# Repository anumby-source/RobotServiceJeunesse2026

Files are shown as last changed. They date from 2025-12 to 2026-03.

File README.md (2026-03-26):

# Projet RobotServiceJeunesse2026

# Réflexions préparatoires pour le projet Jeunesse 2026

Le projet Jeunesse aura lieu dans une 1/2 journée dans les vacances pâques 2026 à choisir. 
Faire attention pour la durée: discuter avec les organisateurs pour obtenir réellement les 3 heures de le demie journée.

Principe: On garde le proto de l'année dernière mais avec quelques corrections (et/ou améliorations)

- Meilleurs moteurs plus rapides (choix des roues)
- Mener des tests pour fiabiliser l'utilisation de Esp now
- choisir le CPU de base: Esp32 s2 s3? C3?
  - impact: nombre de DIOs
  - tester la nécessité d'une vraie antenne
  - Nouveau proto (encombrement)
- Pilotage
- nouveau design pour le circuit
- utilisation d'un Microphone?
- IA ? Reconnaissance de symboles plutôt que caractères

- Refaire la télécommande. tests de Fiabilité
- Pb de multicanal sur la communication: tests
- utilisation de Powerbank 5V
- Reconnaissance par le k210 ?

## Organisation:
- distribuer les rôles pour les éléments à re-tester (moteurs, communication, reconnaissance, circuit, achats)
- mettre en place un Github 2026

# Benchmark ESP-now sur ESP32 S3

En menant mon benchmark esp-now j'ai compris qu'il faut flasher micropython >= 1.26 (au moins) car c'est à partir de cette version de micropython que Esp-now, est inclus dans micropython.
Par défaut 1.19 était flashé sur le ESP32-S3.
Pas grave mais il suffisait de le savoir.

# Convention d'identification pour ESP32-S3

ESP32-S3-N8R2

Chez Espressif, cette nomenclature signifie :

N8 → 8 MB de Flash
R2 → 2 MB de PSRAM

# IDF and HEAP in ESP32

list_of_tuples = esp32.idf_heap_info(esp32.HEAP_DATA )

each tuple in list_of_tuples is:
- total bytes
- the free bytes
- the largest free block

# Discussion mardi 13 janvier sur projet Jeunesse

- Alimentation Powerbank ok 18650 (vérifications pour la stabilité cependant)
- Gilles a préparé une nouvelle implémentation de l'ensemble, avec S2 (avec l'antenne améliorée)
  + une résistance de charge 
  + Logiciel sans changement 
  + Une néo pixel qu'il faudra intégrer au soft

- Détection de symboles avec k210 plutôt que nom des villes 

- Possibilité de fournir la version aux jeunes avec un capteur de distance à la place du k210

- on garde des options avec esp32 s3 cam ? mais l'option de base préférée est celle qui garanti le moindre changements

- Pb de la télécommande 
    + Batterie changer ?
    + version Ttgo esp32 avec afficheur + chargeur 
    + Ajouter vitesse lente.

# Programme de base pour le jeu Robot

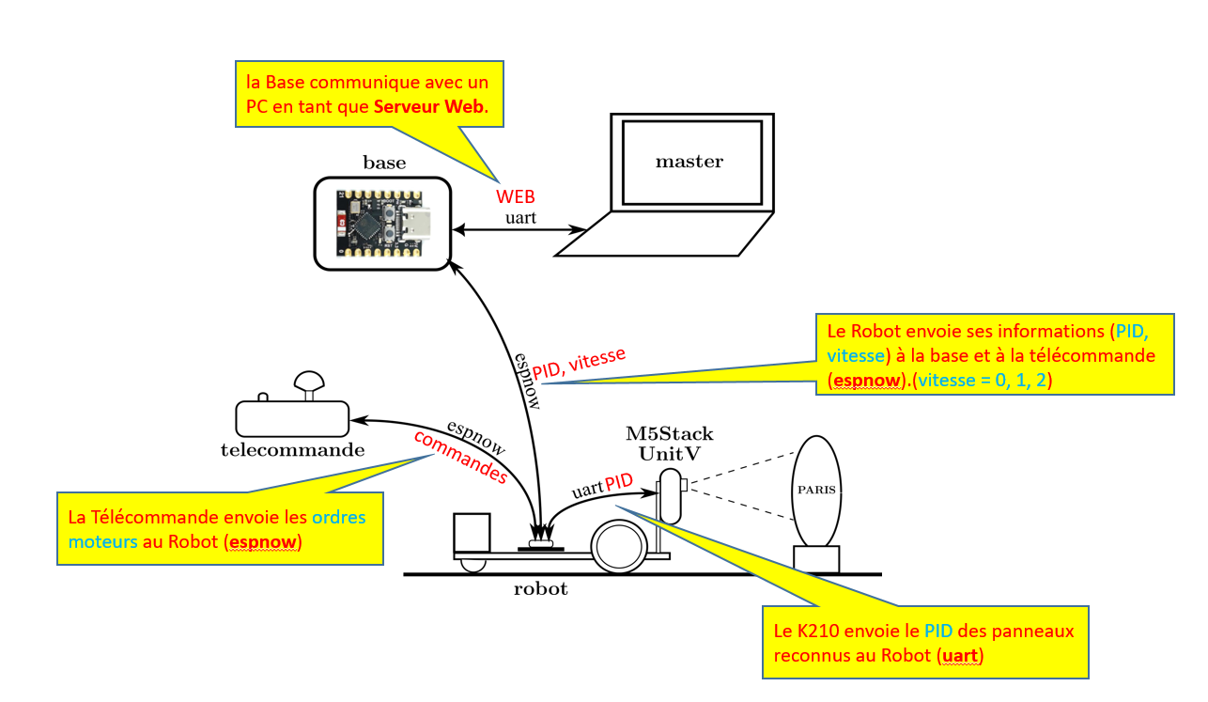
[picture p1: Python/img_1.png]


Le programme base.py implémente la connexion entre le cpu du Robot et l'écran de contrôle

Le principe de base consiste à recevoir les messages (canal espnow) qui reflètent les panneaux routiers détectés par la caméra du K210.

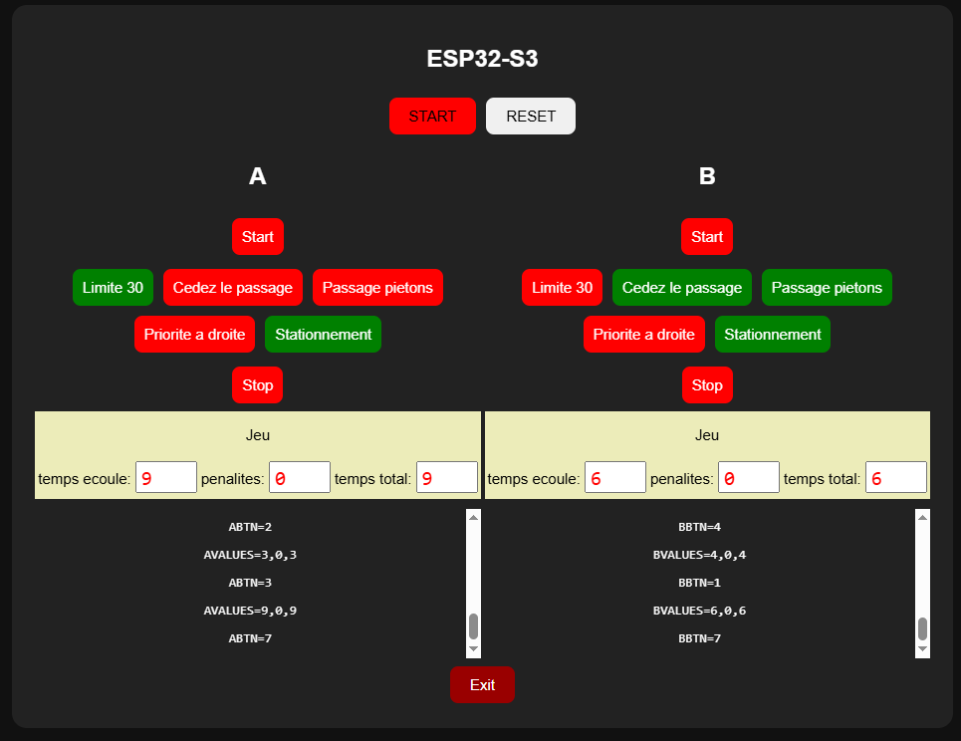
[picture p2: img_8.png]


l'IHM de base.py montre tous les messages reçus et décode ces messages en allumant les boutons des panneaux.

Etat d'avancement du programme de base:

- le programme base tourne sur un esp32
- c'est un serveur Web utilisant les SSE
- il est connecté espnow avec les CPUs de deux robots.
  => il faudra assurer que la mac adresse du ESP32 de base est déclarée
     dans le fichier mac_addr 
- actuellement la base est sensible aux valeurs d'ID de panneaux transférés via espnow mais il est 
  aussi sensible de façon équivalente aux boutons équivalents de l'IHM de la base
- il reste à ajouter la propagation des valeur de la vitesse (0, v1, v2) qui est nécessaire pour
  faire fonctionner le protocole du jeu.
- actuellement du protocole de jeu est simplifié
     - Le bouton global "START" lance les deux jeux pour les deux robots
     - on attend la reconnaissance du panneau "start"
     - ensuite tous les panneaux sont reconnus mais n'influencent pas le jeu
     - en suite la reconnaissance de "stop" arrête le jeu
     - l'IHM met à jour le temps courant de parours
     - on ne comptabilise pas le pénalités pour l'instant
     - le bouton global "RESET" réinitialise les deux jeux

Les messages espnow fournissent automatiquement l'adresse MAC du robot appelant.
Le logiciel va attribuer le premier robot ayant parlé au côté "A" et le deuxième au côté "B"

# Logique des événements dans le programme base.

On gère plusieurs sources d'événements:
- il y a ce qui vient de espnow: ce sont des événements produits par les robots. Ces messages contienent:
   - Les ID des panneaux reconnus par le K210
   - l'état du moteurs (=> vitesse=0, v1, v2)
   - avec le format: "PID=ID,vitesse"
- il y a ce qui vient de l'IHM (à travers des appels (fetch("key=data"))

Les événements espnow sont mis en queue dans la queue "queue_espnow", qui est elle-même exploitée (dépilée) par la fonction
"espnow_dispatcher", qui transforme les evts "espnow" en evts SSE. Ces événements ont le format "PID=data"

Ces événements produisent tous des messages SSE, qui sont mis en queue d'attente dans la queue "queue_sse".
La queue "queue_sse" est dépilée par la fonction du serveur "Server.sse_broadcaster()".
Les événements SSE sont traités dans le script JS dans le fonction du gestionnaire "EventSource" 
  - déclarée par "var E = new EventSource('/events');"
  - qui est appelé par "E.onmessage = function(e) {...}"
  - un événement SSE transféré de espnow va émuler un click par l'appel interne de la fonction "onclick" attachée aux boutons

Cette fonction produit en particulier des actions directes sur des éléments de l'IHM du style "document.getElementById(<element_id>).style.background='red';"

L'IHM est structurée avec:
- des éléments de contrôle généraux
    - pour démarrer le jeu ou réinitialiser les données du jeu
- une table à deux colonnes: pour chacun des deux joueurs:
    - des boutons pour émuler les panneaux si on fonctionne sans connexion avec les robots ou pour refléter les panneaux effectivement reconnus
    - un panneau des valeurs du jeu, mises à jours en temps réel.

Routes:

- START: démarrage général du jeu
- RESET: réinitialsation générale du jeu
- APID: message espnow du robot A
- BPID: message espnow du robot B
- ABTN: message IHM du joueur A
- BBTN: message IHM du joueur B
- AVALUES: valeurs jeu du joueur A
- BVALUES: valeurs jeu du joueur B

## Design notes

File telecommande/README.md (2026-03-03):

# Telecommande 2026

L'évolution essentielle par rapport à la version 2025 est le remplacement de l'ESP32C3 par la carte TTGO T-Display qui inclue :
- un ESP32
- un afficheur ST7789 240x135
- un connecteur d'accu Li-Po ou Li-ion pour l'alimentation, ainsi qu'un circuit de charge de l'accu

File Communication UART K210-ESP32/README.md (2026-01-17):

# Mise en place d'une communication série entre K210 et un ESP32

Dans le but de mettre en place une meilleure ergonomie de l'apprentissage pour des figures avec le K210, on teste la communication série UART.

On prépare une petite configuration

- un ESP32-C3 Super Mini 
- un K210 UnitV
- une diode (avec une résistance) pour visualiser le trafic
- deux logiciels 
  - envoi de messages par le ESP32
  - réception par le K210

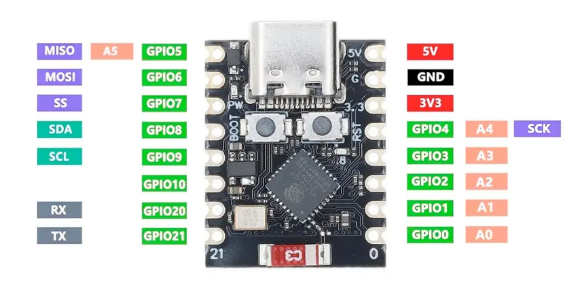
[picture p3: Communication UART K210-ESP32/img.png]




- on utilise la broche 5 (TX) du ESP32-C3
- une diode est installée pour visualiser le trafic
- on connecte la broche 5 du ESP32 à la broche 1 (RX) du connecteur Grove

# Exécution:

sender.py:

    821971436 sent message from ESP32 #1 21
    821971437 sent message from ESP32 #2 21
    821971438 sent message from ESP32 #3 21
    821971439 sent message from ESP32 #4 21
    821971440 sent message from ESP32 #5 21
    821971441 sent message from ESP32 #6 21
    821971442 sent message from ESP32 #7 21
    821971443 sent message from ESP32 #8 21

receiver.py

    line b'message from ESP32 #37message from ESP32 #38'
    line b'message from ESP32 #39'
    line None
    line None
    line None
    line None
    line None
    line None
    line None
    line b'message from ESP32 #40'
    line None
    line None
    line None
    line None
    line None
    line None
    line b'message from ESP32 #41'
    line None
    line None
    line None
    line None
    line None
    line None
    line None
    line b'message from ESP32 #42'
    line None
    line None
    line None
    line None
    line None
    line None
    line None
    line b'message from ESP32 #43'
    line None
    line None
    line None
    line None
    line None

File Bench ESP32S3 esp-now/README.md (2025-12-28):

# Tests esp-now entre deux ESP32S3

## Configuration: deux ESP32S3 
- **boost.py**
  - boost est commun aux deux ESP32S3. Il contient la configuration MAC des deux ESP32S3
- **ESPA**:
  - ESPA est configuré avec son main.py puis est alimenté par une powerbank
  - ESPA attend le message "START" puis envoie 10 messages "OK" à l'émetteur du START
- **ESPB**:
  - ESPB envoie "START" à ESPA puis reçoit des messages de la part de ESPA. On relance la boucle.

    MAC= b'\xd0\xcf\x13D\x0b\x1c'
    MACA= b'\xd0\xcf\x13C\xa7$'
    MACB= b'\xd0\xcf\x13D\x0b\x1c'
    MAC= b'\xd0\xcf\x13D\x0b\x1c' MACA= b'\xd0\xcf\x13C\xa7$' MACB= b'\xd0\xcf\x13D\x0b\x1c'
    Je suis MACB
    WiFi prêt, MAC : b'\xd0\xcf\x13D\x0b\x1c'
    Envoi de START à ESP A...
    START envoyé !
    Réception des OK...
    OK reçu: 1 / 10
    OK reçu: 2 / 10
    OK reçu: 3 / 10
    OK reçu: 4 / 10
    OK reçu: 5 / 10
    OK reçu: 6 / 10
    OK reçu: 7 / 10
    OK reçu: 8 / 10
    OK reçu: 9 / 10
    OK reçu: 10 / 10
    Timeout ou message inconnu
    Réception terminée !
    Envoi de START à ESP A...
    START envoyé !
    Réception des OK...
    OK reçu: 1 / 10
    OK reçu: 2 / 10
    OK reçu: 3 / 10
    OK reçu: 4 / 10
    OK reçu: 5 / 10
    OK reçu: 6 / 10
    OK reçu: 7 / 10
    OK reçu: 8 / 10
    OK reçu: 9 / 10
    OK reçu: 10 / 10
    Timeout ou message inconnu
    Réception terminée !

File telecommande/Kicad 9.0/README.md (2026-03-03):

# Fichiers Kicad du pcb telecommande

<p align="center"> 
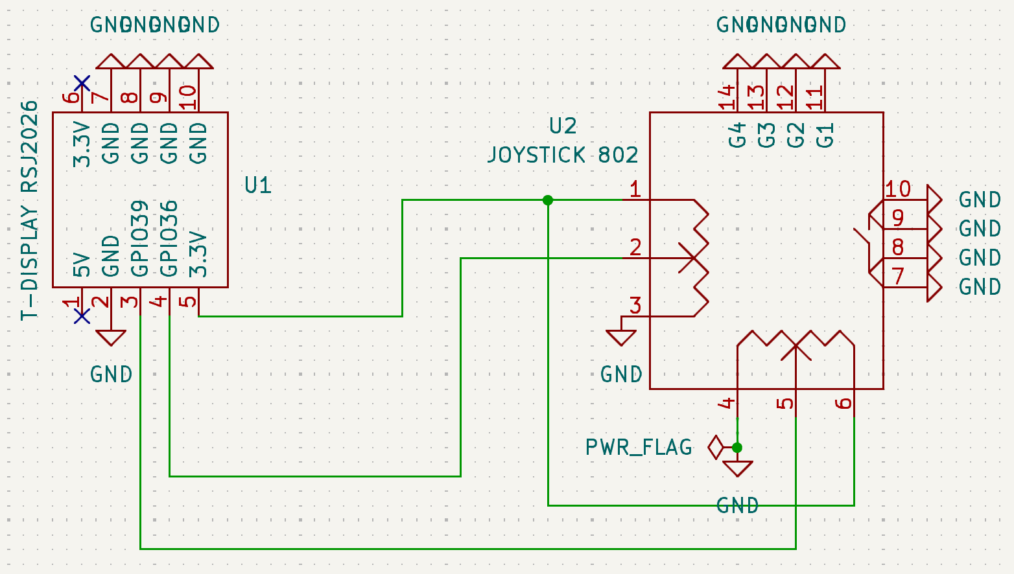
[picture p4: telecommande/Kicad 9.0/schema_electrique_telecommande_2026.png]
   
<p/>

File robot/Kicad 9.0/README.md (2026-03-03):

# Fichiers Kicad du pcb robot

<p align="center"> 
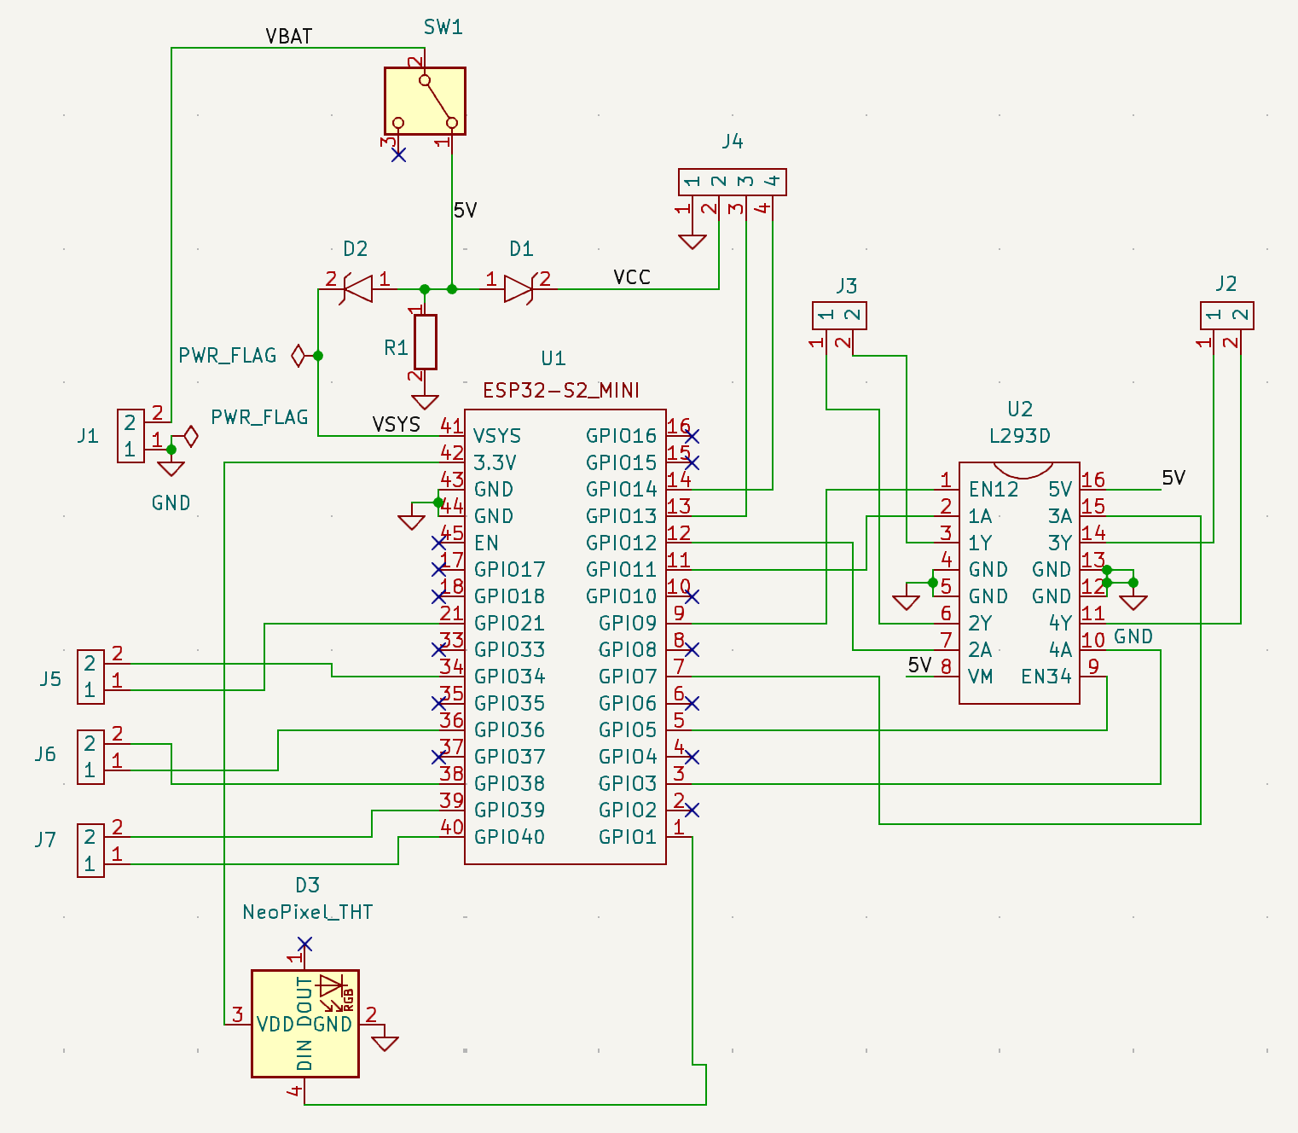
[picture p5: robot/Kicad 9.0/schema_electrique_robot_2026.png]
   
<p/>

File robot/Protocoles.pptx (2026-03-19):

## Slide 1

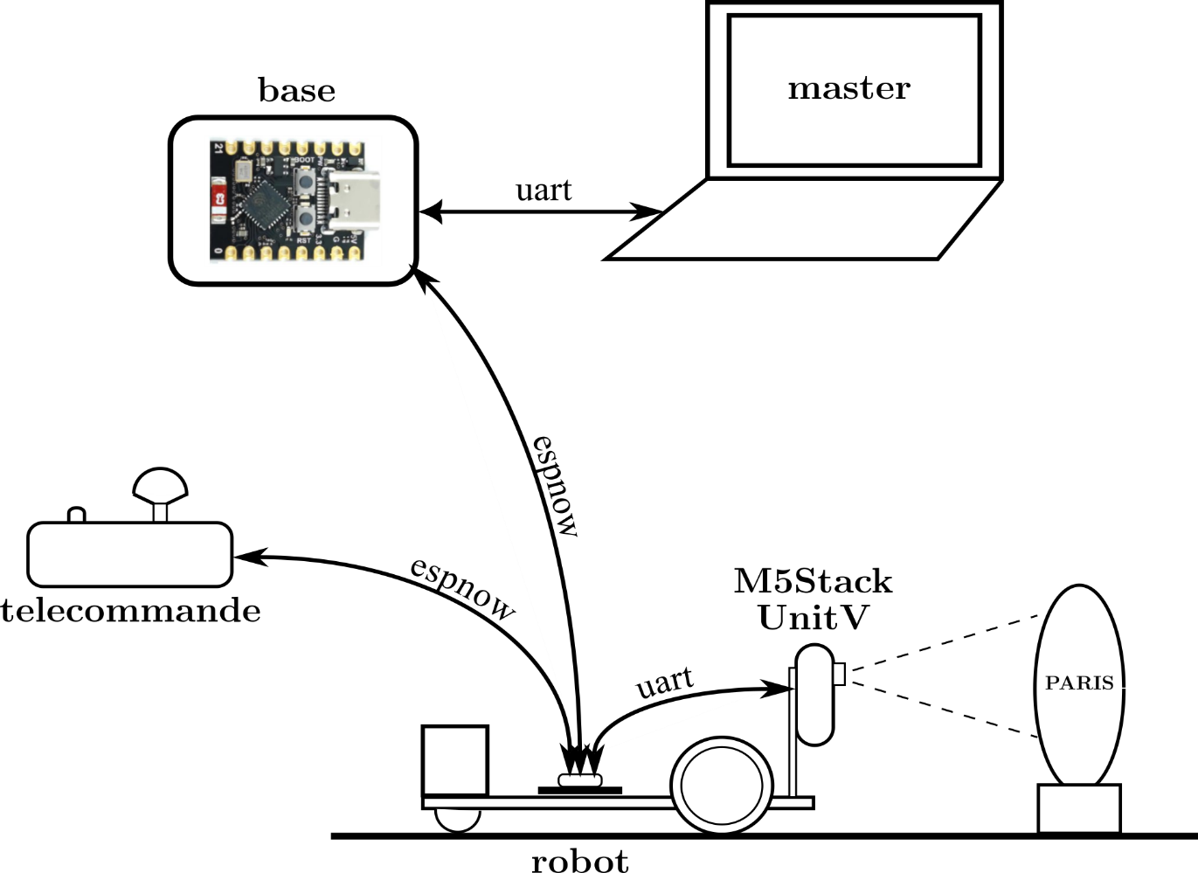
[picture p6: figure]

WEB

PID, vitesse

commandes

PID

la Base communique avec un PC en tant que Serveur Web.

Le Robot envoie ses informations (PID, vitesse) à la base et à la télécommande (espnow).(vitesse = 0, 1, 2)

La Télécommande envoie les ordres moteurs au Robot (espnow)

Le K210 envoie le PID des panneaux reconnus au Robot (uart)

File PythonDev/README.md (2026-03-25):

# Programme de base pour le jeu Robot



Le programme base.py implémente la connexion entre le cpu du Robot et l'écran de contrôle

Le principe de base consiste à recevoir les messages (canal espnow) qui reflètent les panneaux routiers détectés par la caméra du K210.

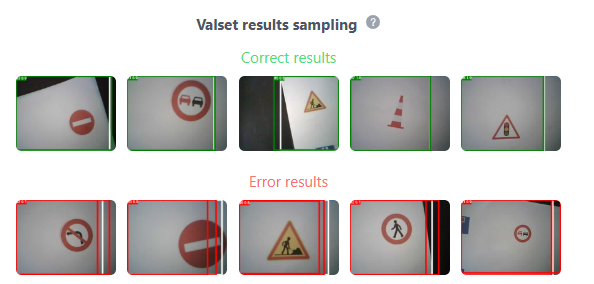
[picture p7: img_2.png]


l'IHM de base.py montre tous les messages reçus et décode ces messages en allumant les boutons des panneaux.

Etat d'avancement du programme de base:

- le programme base tourne sur un esp32
- c'est un serveur Web utilisant les SSE
- il est connecté espnow avec le CPU du robot.
  => il faudra assurer que la mac adresse du ESP32 de base est déclarée
     dans le fichier mac_addr 
- actuellement la base est sensible aux valeurs d'ID de panneaux transférés via espnow mais il est 
  aussi sensible de façon équivalente aux boutons équivalents de l'IHM de la base
- il reste à ajouter la propagation des valeur de la vitesse (0, v1, v2) qui est nécessaire pour
  faire fonctionner le protocole du jeu.
- actuellement du protocole de jeu est simplifié
   - on attend la reconnaissance du panneau "start"
   - ensuite tous les panneaux sont reconnus mais n'influence pas le jeu
   - en suite la reconnaissance de "stop" arrête le jeu
   - l'IHM met à jour le temps courant de parours
   - on ne comptabilise pas le pénalités pour l'instant

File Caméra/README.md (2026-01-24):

# Caméra

Positionnement de la caméra pour suivre le déplacement conforme

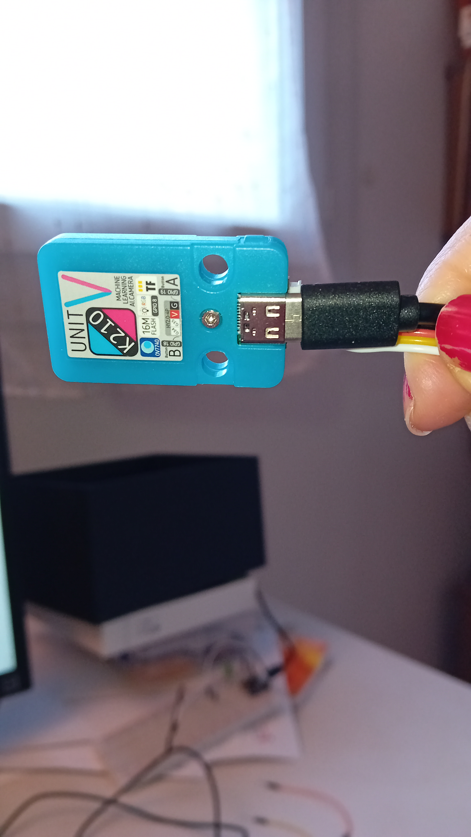
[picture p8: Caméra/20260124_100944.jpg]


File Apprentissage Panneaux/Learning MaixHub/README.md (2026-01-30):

# Apprentissage par l'outil MaixHub

https://maixhub.com/model/training/project

- Créer un projet

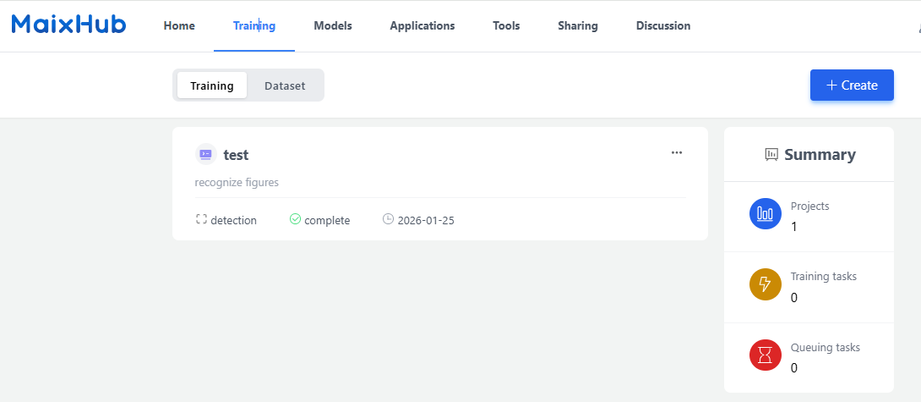
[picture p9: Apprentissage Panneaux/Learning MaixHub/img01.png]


- pour collecter des données, on va utiliser l'outil d'annotation automatique https://maixhub.com/model/training/project
- lorsque l'on crée le dataset on doit choisir "détection"

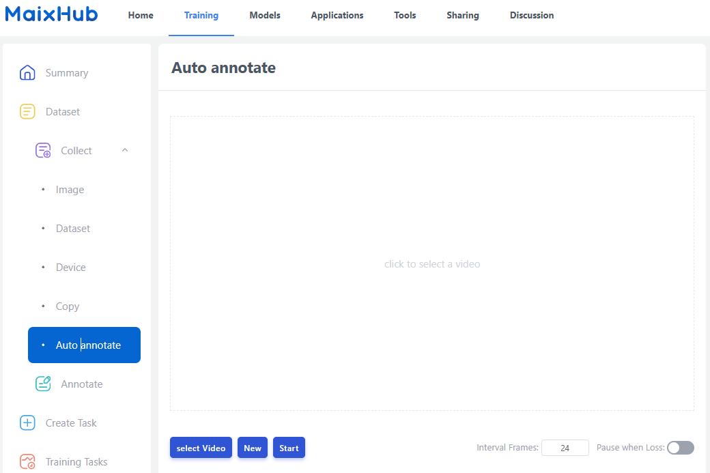
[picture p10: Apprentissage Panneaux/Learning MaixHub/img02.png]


   - créer des images papier, une pour chacune des images sur laquelle l'on veut entraîner le modèle
   - créer des vidéos (par le téléphone par exemple) sur chacune de ces images cibles. Le logiciel analysera ensuite ces vidéos, en extrayant automatiquement des vues fixes (24 images/s) en les associant à un label
   - chaque vidéo consiste à montrer une des images cible sous différents angles, différents agrandissement, différents cadrages
   - la durée de la vidéo doit permettre un nombre suffisant de vues individuelles (environ 50 vues pour une vidéo de 50s)
   - le training nécessite au moins 50 vues différentes
   - transférer les vidéos vers le PC
   - saisir une vidéo

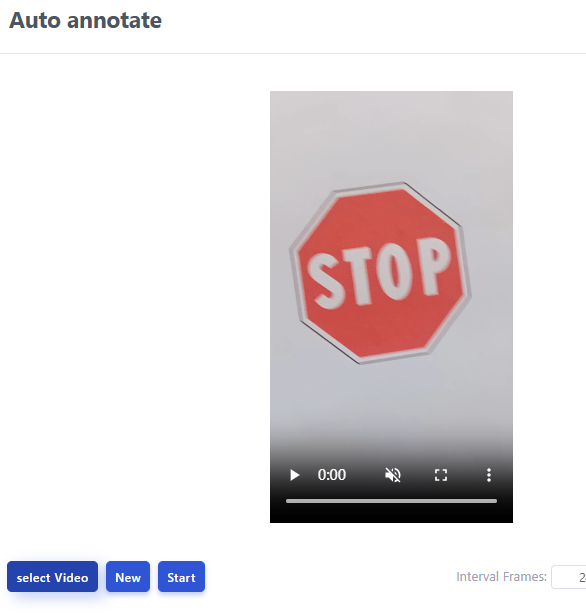
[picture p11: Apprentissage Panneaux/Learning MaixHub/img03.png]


   - avec l'option "new", configurer l'extraction des vues en définissant le label associé à toutes ces vues, ainsi que le cadrage par défaut

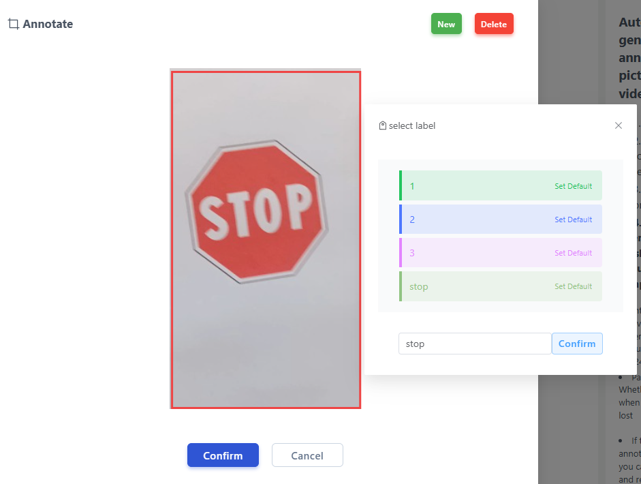
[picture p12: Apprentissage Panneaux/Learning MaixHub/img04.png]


   - lancer l'extraction avec l'option "start"

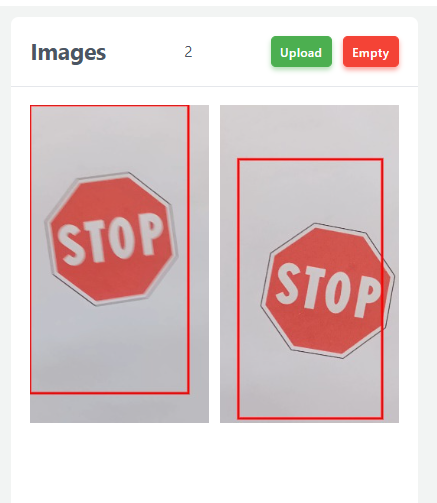
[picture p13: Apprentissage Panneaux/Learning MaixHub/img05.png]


   - terminer l'extraction avec l'option "Upload" et répéter cette opération pour toutes les vidéos de toutes les images à entraîner. Associer les labels de façon appropriée.

   - lancer la tâche d'entraînement en sélectionnant la plateforme (nncase pour K210) et les actions d'amélioration du set puis "start"

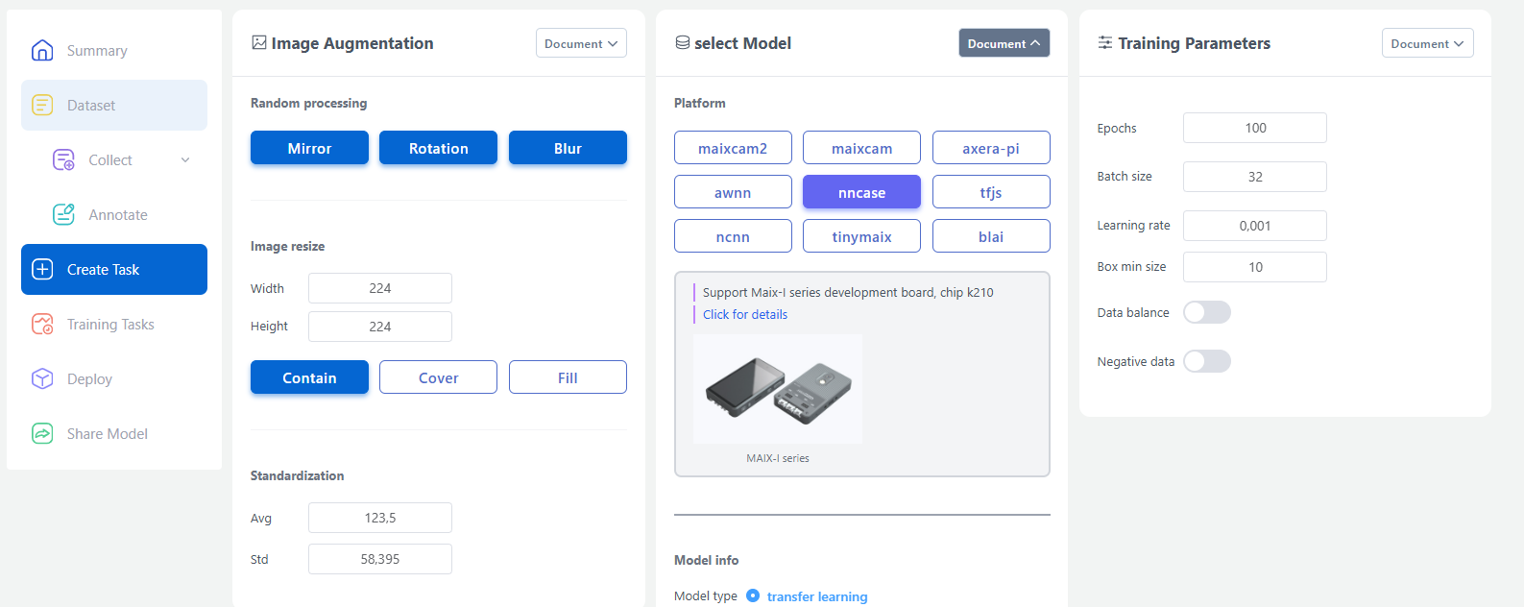
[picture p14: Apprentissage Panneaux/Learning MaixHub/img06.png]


   - observer le déroulement de la tâche d'entraînement avec l'option "Training task"

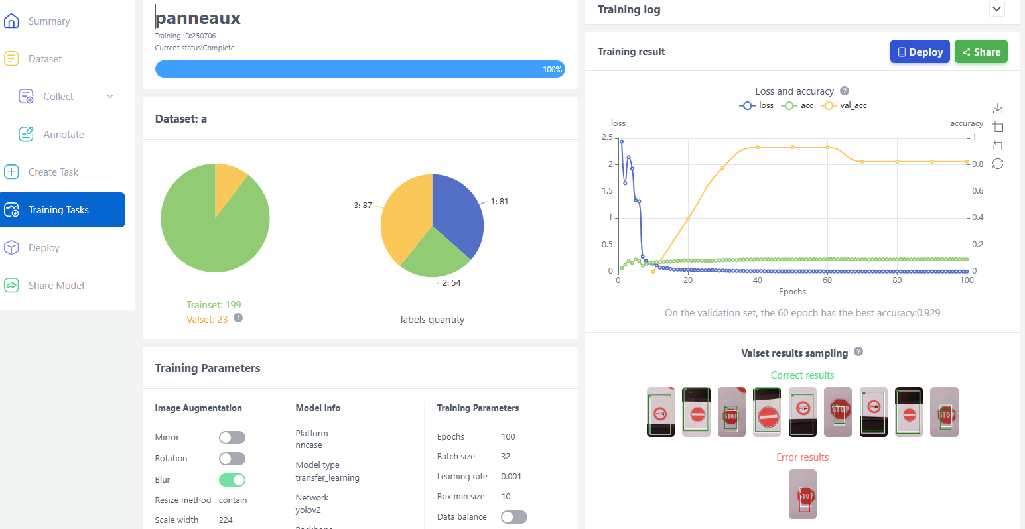
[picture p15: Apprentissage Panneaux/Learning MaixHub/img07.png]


   - Créer le kit avec le modèle entrainé avec l'option "Deploy"

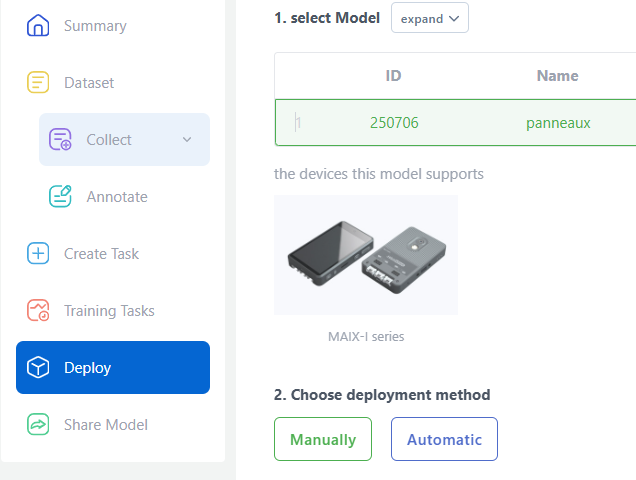
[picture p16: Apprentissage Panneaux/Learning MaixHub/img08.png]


Ce kit contient :
    - le modèle (fichier *.kmodel)
    - un fichier "main.py" que l'on devra modifier pour différentes options. Par exemple, on peut envoyer par UART le résultats des classifications.
    - il est recomandé de corriger les adresses de l'UART 

    fm.register(35, fm.fpioa.UART1_TX, force=True)
    fm.register(34, fm.fpioa.UART1_RX, force=True)

et configurer l'adresse de chargement du modèle:

    main(anchors = anchors, labels=labels, model_addr=0x300000, lcd_rotation=0)

- Installer le modèle avec l'outil "kflash_gui" à l'adresse "0x300000"
- exécuter le programme modifé selon vos souhaits
- les résultats sont envoyés sous le format:

      93:28:99:176:0:0.54:1

  - coordonnées de la zone de l'image détectée
  - id de la classe
  - probabilité de réussite de la détection
  - label identifié

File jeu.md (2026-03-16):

# Fonctionnement du simulateur de jeu

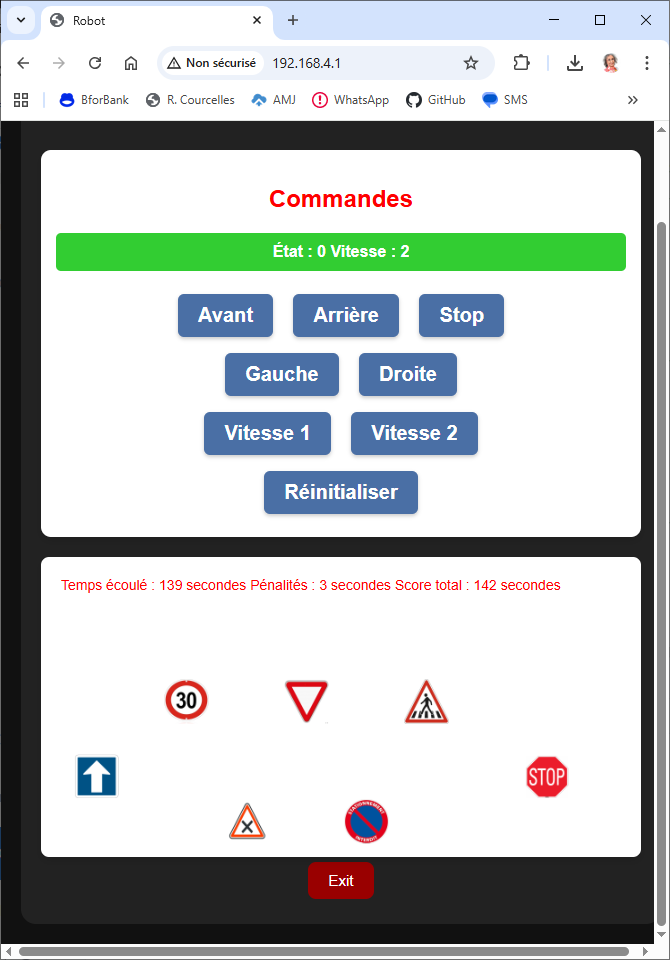
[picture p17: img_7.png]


Le programme Python/control.py permet de simuler le jeu du robot.
(notez que ce programme a besoin de la librairie Python/server.py)

- Ce programme fonctionne sur un ESP32
- le programme démarre un serveur web avec deux zones IHM:
  - Zone de commandes qui émule la télécommande qui pilote les moteurs du Robot.
  - Zone de contrôle qui émule le trajet à parcourir par le robot.

## La zone de commandes

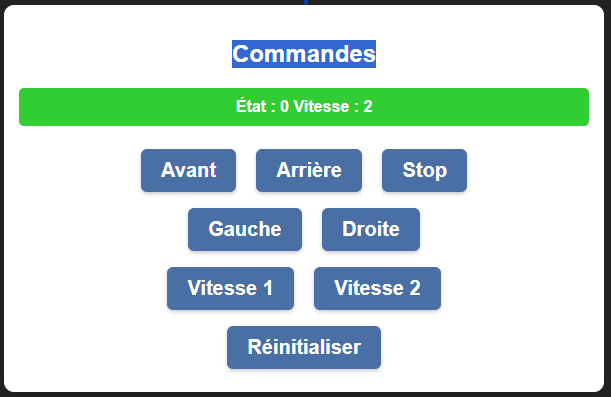
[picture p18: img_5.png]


- émule la télécommande avec les commandes habituelles (y compris le choix des vitesses 1 et 2)
- montre aussi la commande de réinitialisation générale
## La zone de contrôle

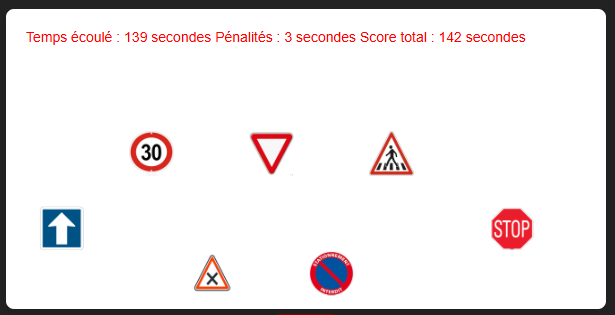
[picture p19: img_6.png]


- les panneaux à installer sur le trajet sont visualisés (sans préoccupation de leur localisaion réelle)
- cliquer sur un panneau émule la reconnaissance par le K210 (le panneau apparait encadré en rouge)
- une ligne d'information en haut de la zone donne les états du jeu (temps écoulé, pénalités, temps total)

Règle du jeu actuel:

- le jeu démarre en cliquant le panneau de la flèche bleue. Ceci démarre le jeu et initialise le temps et les pénalités
- différentes situations sont testées et apportent éventuellement de pénalités de temps
  - 30 exige que le robot soit en vitesse 1
  - laisser le passage, priorité à droite exige que le robot soit en vitesse 1
  - passage piéton stoppe le robot pendant quelques secondes
  - stationnement interdit exige que le robot ne soit pas à l'arrêt
  - stop arrête le jeu

## Evolutions futures

L'objectif est de connecter réellement l'ESP32 pilotage des moteurs (via espnow) avec le K210
Ainsi 
- les commandes reflètent les commandes envoyées par la télécommande
- les détections reflètent les détections du K210

Seule la commande "Réinitialiser" restera accessible par l'opérateur

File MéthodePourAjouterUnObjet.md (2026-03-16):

# Méthode pour ajouter un nouveau panneau routier 

Choisir un panneau et imprimez-le. Identifier un label associé à l'objet, qui doit être un nouveau label ajouté à la liste des labels déjà entraînés.

## Création des images du dataset

Utiliser le "ESP32-S3 Cam" en utilisant `Thonny` en exécutant le pogramme `Python\InitDataset.py`

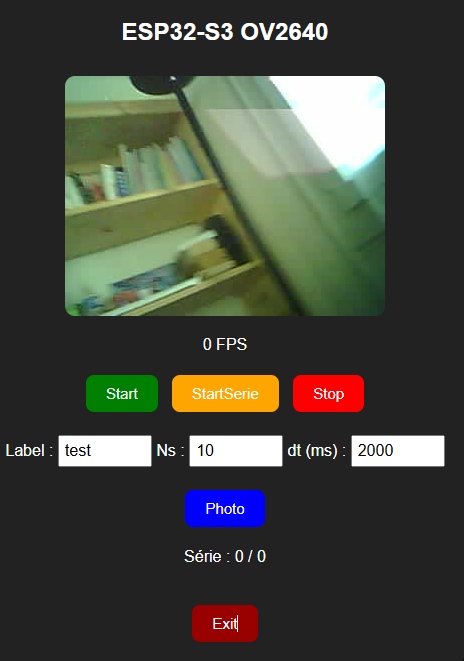
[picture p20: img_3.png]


Ce programme lance un serveur Web `ESP32-CAM` et affiche une page WEB qui propose plusieurs fonctionnalités:
- se connecter sur sur le serveur et afficher la page `192.168.4.1` sur un navigateur
- tester la caméra sur la photo du panneau (options `Start` ou `Photo`)
- lorsque les réglages semblent satisfaisants, 
  - on choisir `Ns=50` vues au moins
  - on choisit le label
  - lancer une série de captures sur la photo choisie, en faisant varier l'orientation, la distance, l'angle de la caméra en s'assurant que l'objet reste visible dans la caméra

Les images sont au départ, générées dans l'espace privé de Thonny. Et les images n'apparaissent 
pas tant que le programme tourne. Il est donc important de quitter le programme puis raffraichir 
l'affichage de l'espace privé de Thonny.

Ensuite, on va transférer toutes les images dans le dossier du PC `dataset/images`

Cette action a généré 50 photos (par label) sous le nom `dataset\images\photo_<label>_<numéro>.jpg`

On doit aussi s'assurer que le set d'images on été déposées dans un dossier `dataset/images/photo*.jpg` (qui contenait déjà les autres photos du dataset complet)

## Ensuite nous allons créer les descriptifs associés à chaque image. 

Pour cela on exécute le programme `Python\detourage.py`

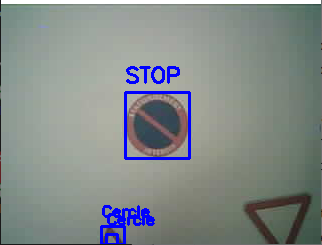
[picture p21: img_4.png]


Pour chaque image, on peut choisir:
- choisir la "Bounding Box" (BB) automatiquement construite, si elle est satisfaisante en cliquant sur cette BB.
- changer la BB en touchant la touche "v" du clavier, puis grâce à la souris, tracer une nouvelle BB
- avec les touches "b" ou "n" du clavier on peut naviguer dans la liste des photos disponibles

Dans tous les cas de sélection, dès que l'on a construit ou sélectionné une BB, on va créer ou mettre à jour le fichier 
d'annotation XML `dataset/xml/photo_<label>_<numéro>.xml` qui contient la BB
mise à jour au format Pascal VOC.

On a ainsi augmenté le dataset de l'ensemble des photos pour ce nouvel objet.

On termine la préparation du dataset en créant un ZIP à partir de dossier `dataset`

## L'étape suivante consiste à générer le modèle avec l'application WEB MaixHub:

- créer un projet P (de type detection)
- créer un dataset P associé
- remplir le dataset à partir du zip créé précédemment (`dataset.zip`) charger dans le projet
- créer une tâche d'apprentissage
- télécharger le résultat sous forme d'un zip contenant le modèle kmodel 
   et un programme main à charger dans le K210

# Bien sûr la dernière étape va consister à télécharger le modèle 
kmodel que l'on installe grâce à l'application `kflash_gui`

Le modèle s'installe à l'adresse `0x300000`

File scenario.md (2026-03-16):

# Parcourir un trajet en respectant les panneaux routiers, avec des pièges et des zones à risque. Le joueur doit éviter les pénalités et optimiser son temps.

- Stop (obligation de s’arrêter N secondes).
- Cédez le passage (ralentir à 30% de la vitesse).
- Limitation de vitesse à 30 km/h (vitesse réduite).
- Passage piétons (obligation de s’arrêter si un "piéton" est présent).
- Priorité à droite (simulée par un autre robot ou un obstacle).
- Interdiction de stationner (zone à éviter).
- Sens giratoire (obligation de tourner dans le sens indiqué).

       [Départ]
              |
              v
       [Limite 30] --> [Passage piétons] --> [Cédez le passage]
              |                              |
              v                              v
       [Sens giratoire] <-- [Priorité à droite] <-- [Interdiction de stationner]
              |
              v
       [Stop] --> [Arrivée]

## Détails des Étapes :

### Départ :

Le joueur démarre son robot et accélère progressivement.

### Limite de vitesse à 30 km/h :

Le robot doit ralentir (vitesse réduite dans le code).
Pénalité : Si le robot dépasse la vitesse, +2 secondes.

### Passage piétons :

Un "piéton" (figurine) est placé aléatoirement.
Règle : Le robot doit s’arrêter si un piéton est présent.
Pénalité : +5 secondes si le robot ne s’arrête pas.

### Cédez le passage :

Le robot doit ralentir (vitesse réduite).
Pénalité : +3 secondes si le robot ne ralentit pas.

### Priorité à droite :

Un obstacle (ex: autre robot ou voiture miniature) arrive de la droite.
Règle : Le robot doit laisser passer l’obstacle.
Pénalité : +4 secondes en cas de collision.

### Interdiction de stationner :

Zone délimitée où le robot ne doit pas s’arrêter.
Pénalité : +3 secondes si le robot s’arrête dans cette zone.

### Sens giratoire :

Le robot doit tourner dans le sens indiqué (flèches dessinées).
Pénalité : +5 secondes si le robot tourne dans le mauvais sens.

### Stop :

Le robot doit s’arrêter complètement pendant 3 secondes.
Pénalité : +5 secondes si le robot ne s’arrête pas.

### Arrivée :

Le chronomètre s’arrête. Le joueur gagne s’il n’a pas accumulé trop de pénalités !

## Règles du Jeu
### But :

- Parcourir le trajet le plus rapidement possible en respectant les panneaux.
- Éviter les pénalités pour obtenir le meilleur score.

### Système de Score :

- Temps de base : Temps mis pour parcourir le trajet.
- Pénalités : Ajoutées au temps de base (voir ci-dessus).
- Bonus : -2 secondes si aucun panneau n’est violé.

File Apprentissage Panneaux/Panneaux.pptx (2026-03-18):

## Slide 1

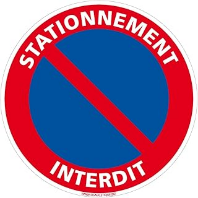
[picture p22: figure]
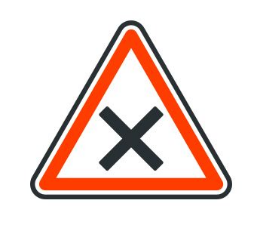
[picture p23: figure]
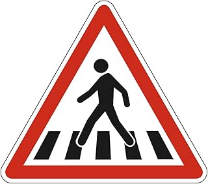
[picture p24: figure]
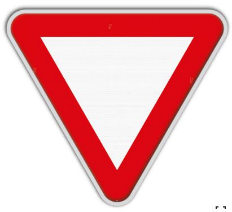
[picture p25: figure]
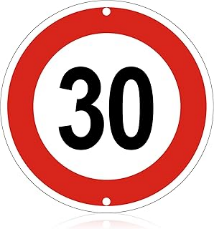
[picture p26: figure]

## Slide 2


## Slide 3

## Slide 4


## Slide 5


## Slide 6

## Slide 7

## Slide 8

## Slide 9

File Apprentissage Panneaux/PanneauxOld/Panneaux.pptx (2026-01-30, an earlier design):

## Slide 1


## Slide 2


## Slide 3


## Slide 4


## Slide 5


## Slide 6


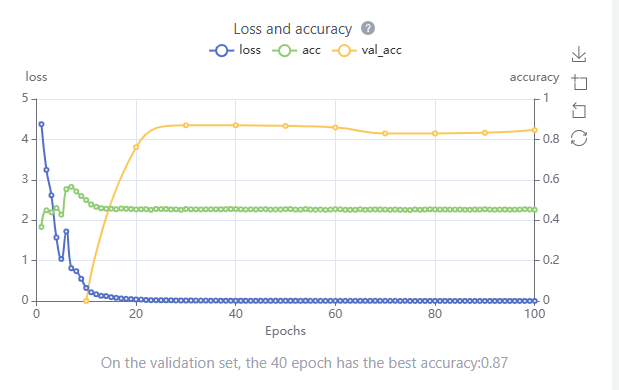
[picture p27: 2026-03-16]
img.png

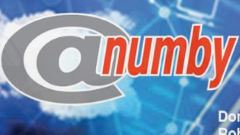
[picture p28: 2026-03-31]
Python/russhughes/demos/Anumby-240x135.png

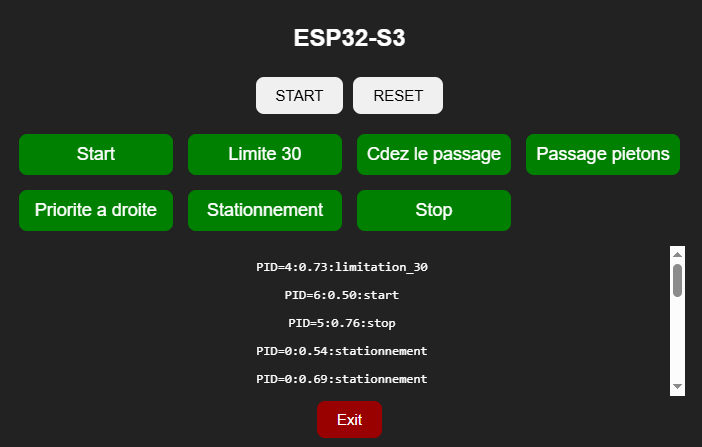
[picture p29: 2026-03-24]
PythonDev/img.png

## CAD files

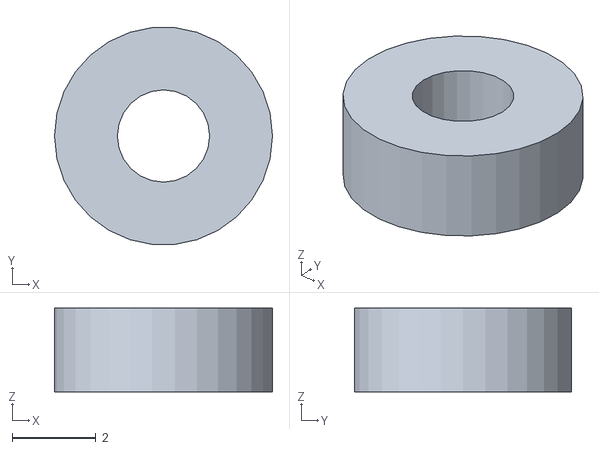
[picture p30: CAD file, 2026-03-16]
robot/impression 3D/entretoise.stl
5.20 x 5.17 x 2.00

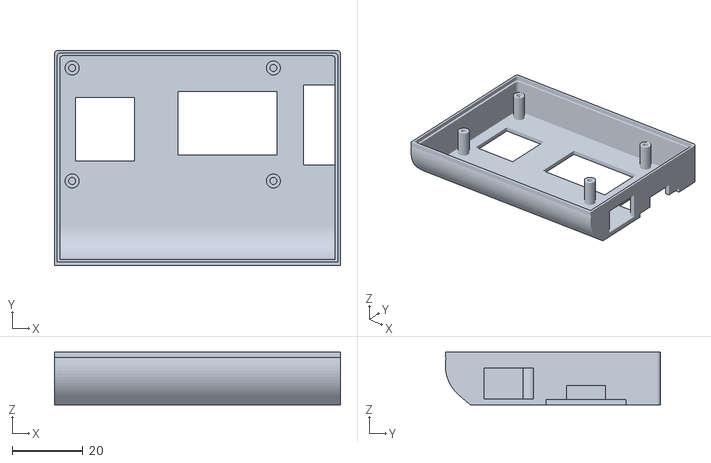
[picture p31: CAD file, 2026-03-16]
telecommande/impression 3D/telecommande bas.stl
81.0 x 61.0 x 15.0

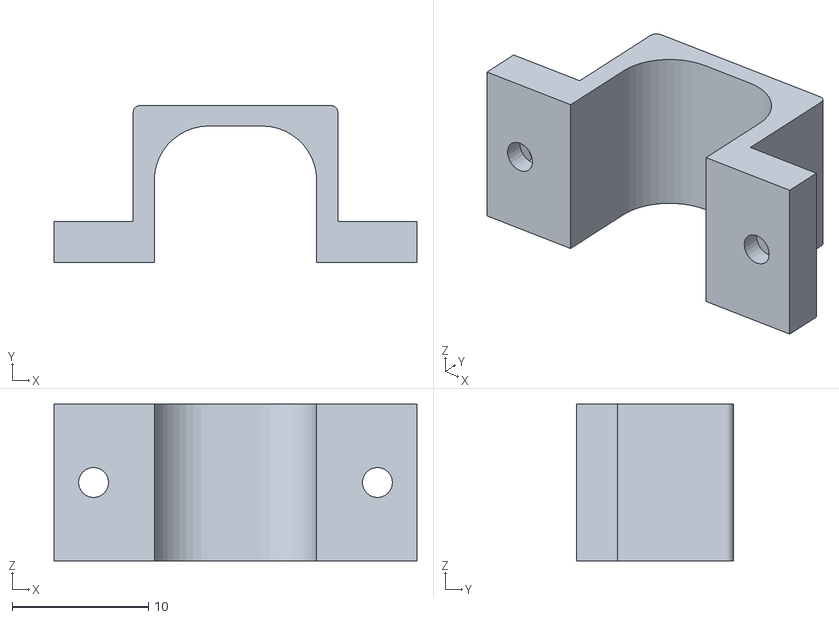
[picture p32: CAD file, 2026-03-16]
robot/impression 3D/bride moteur N20.stl
26.6 x 11.5 x 11.5

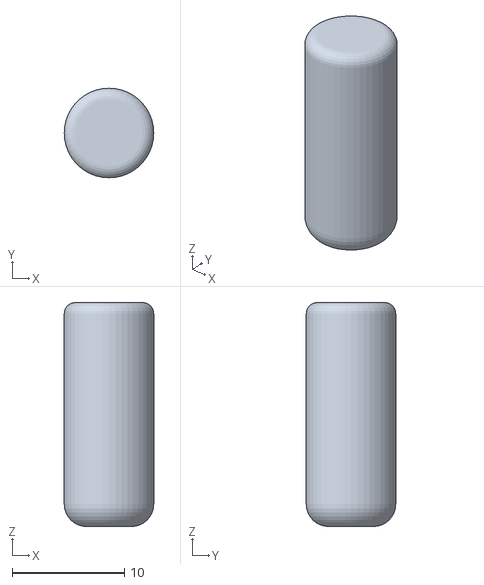
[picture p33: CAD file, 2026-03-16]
telecommande/impression 3D/joystick.stl
8.00 x 8.00 x 20.0

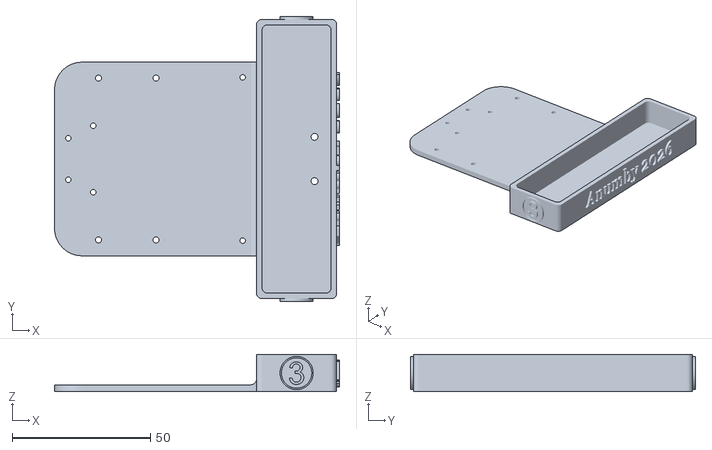
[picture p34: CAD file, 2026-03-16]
robot/impression 3D/chassis.stl
103.0 x 103.0 x 13.5

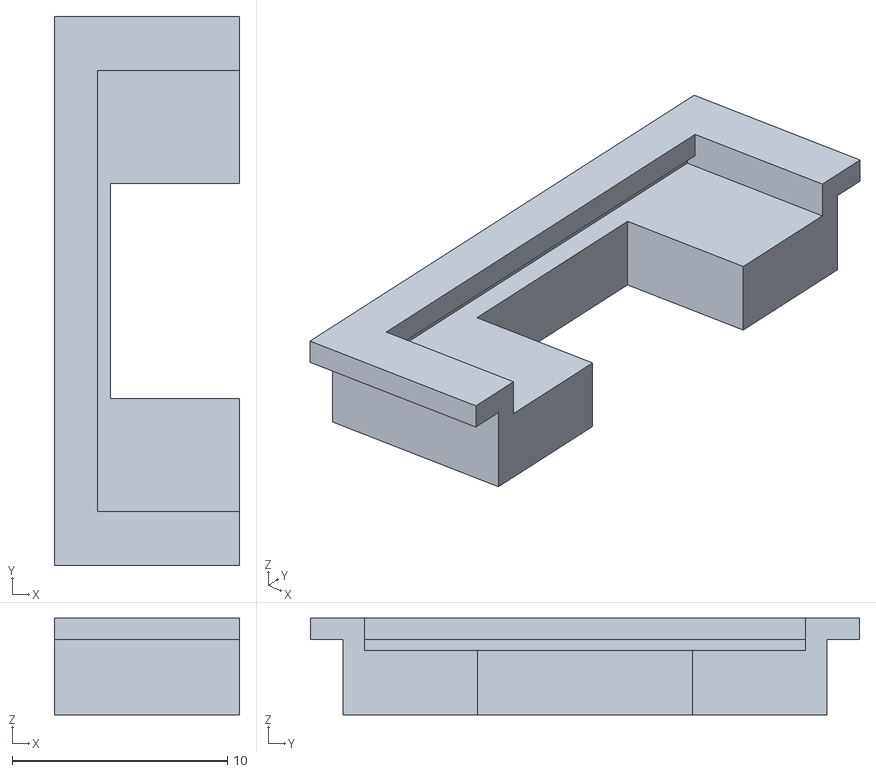
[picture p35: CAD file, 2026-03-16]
telecommande/impression 3D/poussoir.stl
8.60 x 25.5 x 4.50

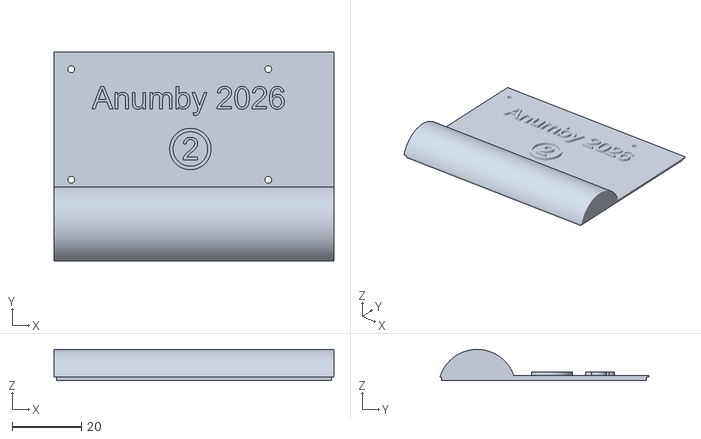
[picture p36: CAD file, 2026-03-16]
telecommande/impression 3D/telecommande haut.stl
81.0 x 60.5 x 9.00

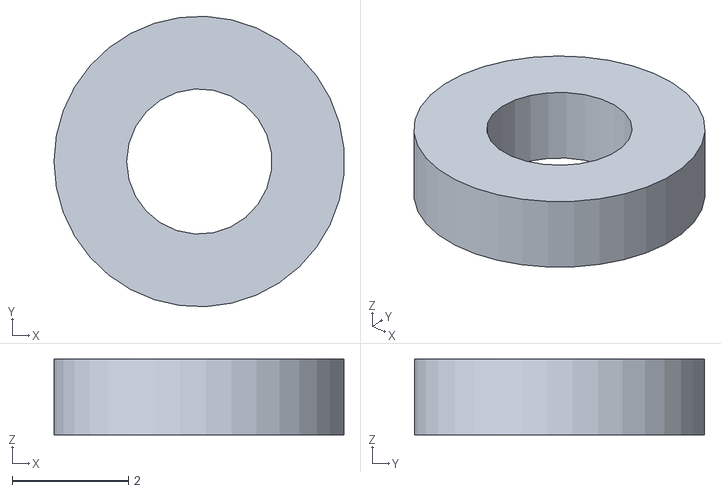
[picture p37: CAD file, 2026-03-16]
telecommande/impression 3D/entretoise.stl
4.99 x 4.99 x 1.30

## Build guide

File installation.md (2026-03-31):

# Procédure d'installation des Robots pour RSJ2026

Les addresses MAC des CPU robots et télécommandes sont à jour dans `Python/mac_addr.py`

Il faut mettre à jour l'addresse MAC du CPU-base dans `Python/mac_addr.py` avant de charger dans les différents CPU

Les programmes `robot.py` ET `telecommande.py` savent détecter automatiquement le numéro de Robot qui leur correspond

## Tous les fichers à installer dans les différents CPUs pour SJ2026:

K210:
- RobotServiceJeunesse2025/Gilles/M5Stack UnitV/M5StickV_Firmware_v5.1.2.kfpkg (charger avec kflash_gui)
- CCW/model-259097.kmodel (charger avec kflash_gui)
- CCW/main.py (charger avec MaixPy IDE et mettre en Boot)

CPU Robot (charger avec Thonny):
- Python/boot.py
- Python/dcMotor.py
- Python/mac_addr.py
- Python/main.py
- Python/robot.py

CPU télécommande  (charger avec Thonny):
- Python/boot.py
- Python/mac_addr.py
- Python/main.py
- Python/st7789_170x320.py
- Python/telecommande.py
- russhughes/*

CPU base  (charger avec Thonny):
- Python/base.py
- Python/server_async.py
- Python/simple_queue.py

La base est un serveur Web avec la procédure habituelle: 
        `SSID="ESP32-CAM"`
        `PASSWORD="12345678"`
        `PORT=80`

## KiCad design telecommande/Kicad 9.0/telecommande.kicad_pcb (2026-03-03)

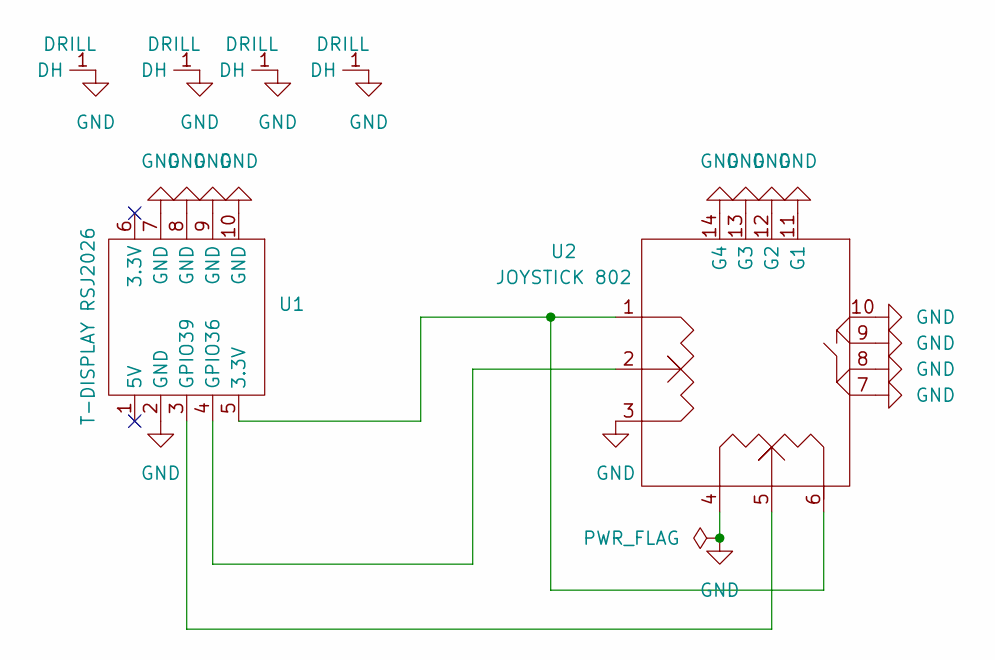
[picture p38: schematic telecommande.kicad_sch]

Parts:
DH1, DH2, DH3, DH4: DRILL; DRILL_HOLE
U1: T-DISPLAY RSJ2026; TTGO T-DISPLAY RSJ2026
U2: JOYSTICK 802; JOYSTICK_MODEL_802

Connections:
GND: DH1.1 (DH), DH2.1 (DH), DH3.1 (DH), DH4.1 (DH), U1.2 (GND), U1.7 (GND), U1.8 (GND), U1.9 (GND), U1.10 (GND), U2.3, U2.4, U2.7, U2.8, U2.9, U2.10, U2.11 (G1), U2.12 (G2), U2.13 (G3), U2.14 (G4)
unnamed: U1.5 (3.3V), U2.1, U2.6
unnamed: U1.4 (GPIO36), U2.2
unnamed: U1.3 (GPIO39), U2.5

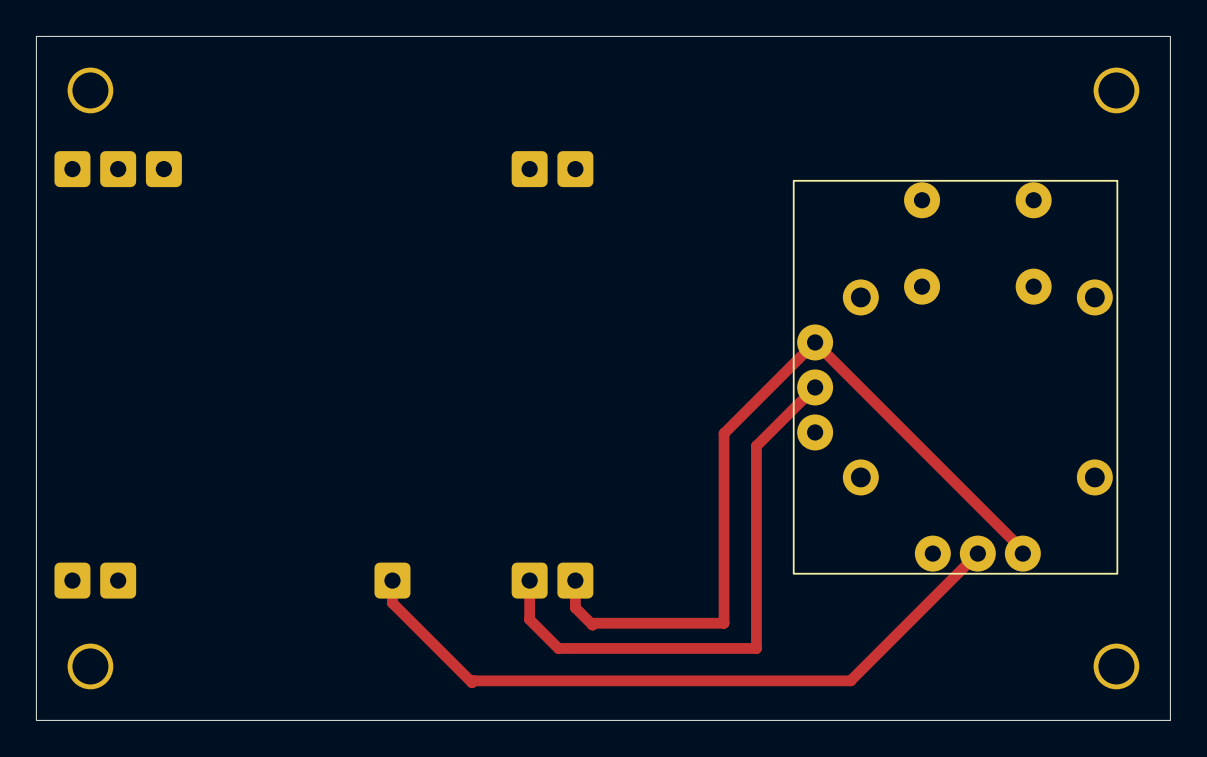
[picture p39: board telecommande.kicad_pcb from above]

Board: 2 copper layers, 63.0 x 38.0 mm, 6 parts (0 on the bottom side), 4 nets.

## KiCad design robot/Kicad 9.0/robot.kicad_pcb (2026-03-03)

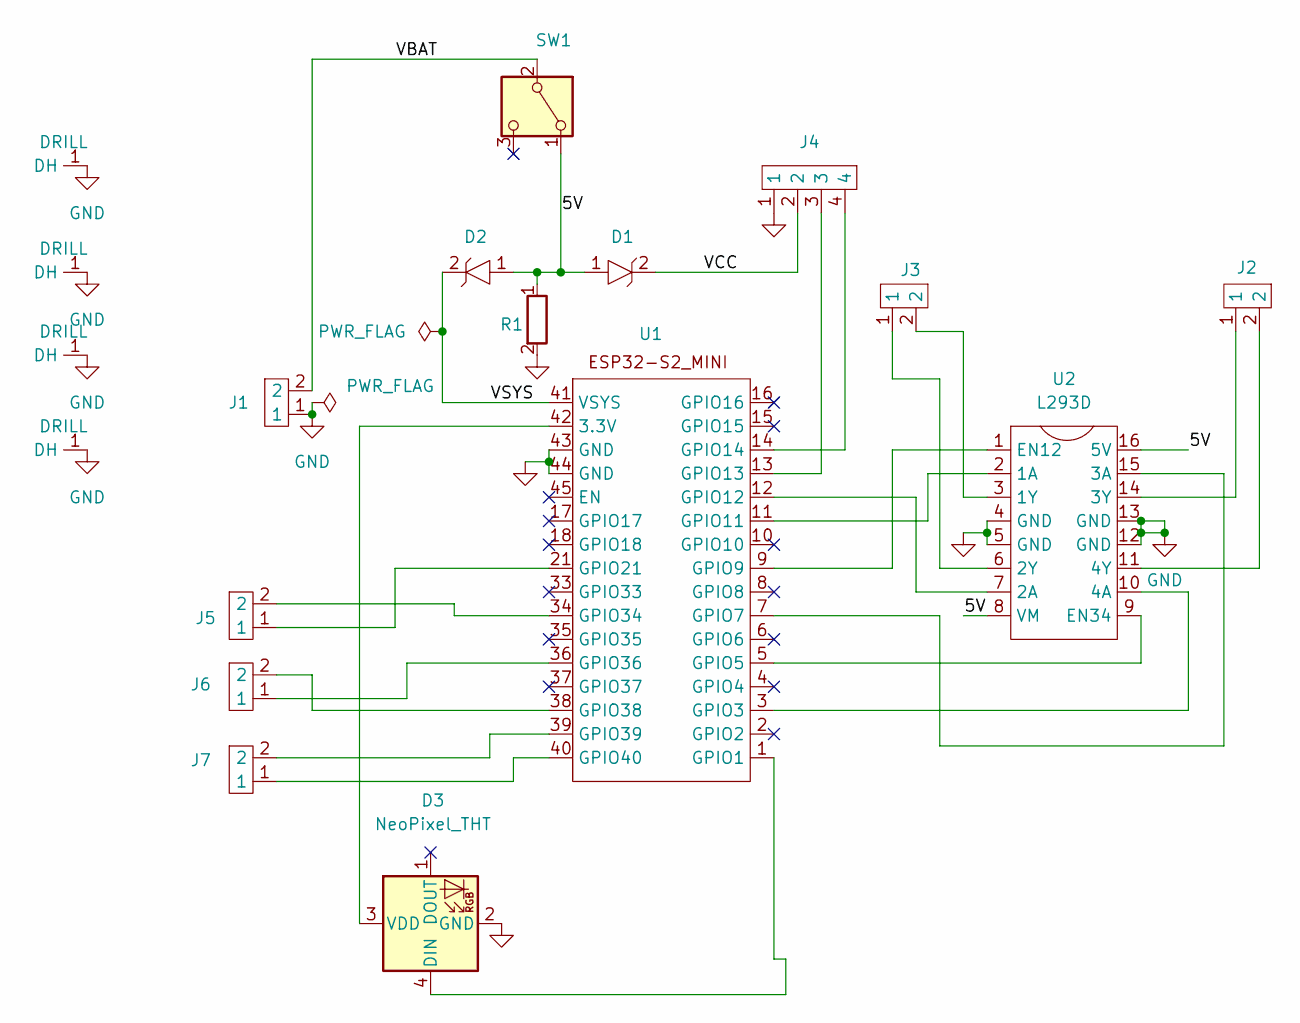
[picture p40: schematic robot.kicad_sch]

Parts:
D1, D2: 1N5818
D3: NeoPixel_THT; NeoPixel
DH1, DH2, DH3, DH4: DRILL; DRILL_HOLE
J1, J2, J3, J5, J6, J7: XH2.54_2P_socket; XH2.54_2P_soc
J4: XH2.54_4P_socket; XH2.54_4P_soc
R1: R_0.25W
SW1: SW_MINI_x1; SW_MINI_X1
U1: ESP32-S2_MINI
U2: L293D

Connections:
/5V: D1.1, D2.1, R1.1, SW1.1 (A), U2.8 (VM), U2.16 (5V)
/VBAT: J1.2, SW1.2 (B)
/VCC: D1.2, J4.2
/VSYS: D2.2, U1.41 (VSYS)
GND: D3.2 (GND), DH1.1 (DH), DH2.1 (DH), DH3.1 (DH), DH4.1 (DH), J1.1, J4.1, R1.2, U1.43 (GND), U1.44 (GND), U2.4 (GND), U2.5 (GND), U2.12 (GND), U2.13 (GND)
unnamed: D3.4 (DIN), U1.1 (GPIO1)
unnamed: D3.3 (VDD), U1.42 (3.3V)
unnamed: U1.3 (GPIO3), U2.10 (4A)
unnamed: U1.5 (GPIO5), U2.9 (EN34)
unnamed: U1.7 (GPIO7), U2.15 (3A)
unnamed: U1.9 (GPIO9), U2.1 (EN12)
unnamed: U1.11 (GPIO11), U2.2 (1A)
unnamed: U1.12 (GPIO12), U2.7 (2A)
unnamed: J4.3, U1.13 (GPIO13)
unnamed: J4.4, U1.14 (GPIO14)
unnamed: J5.1, U1.21 (GPIO21)
unnamed: J5.2, U1.34 (GPIO34)
unnamed: J6.1, U1.36 (GPIO36)
unnamed: J6.2, U1.38 (GPIO38)
unnamed: J7.2, U1.39 (GPIO39)
unnamed: J7.1, U1.40 (GPIO40)
unnamed: J3.2, U2.3 (1Y)
unnamed: J3.1, U2.6 (2Y)
unnamed: J2.1, U2.14 (3Y)
unnamed: J2.2, U2.11 (4Y)

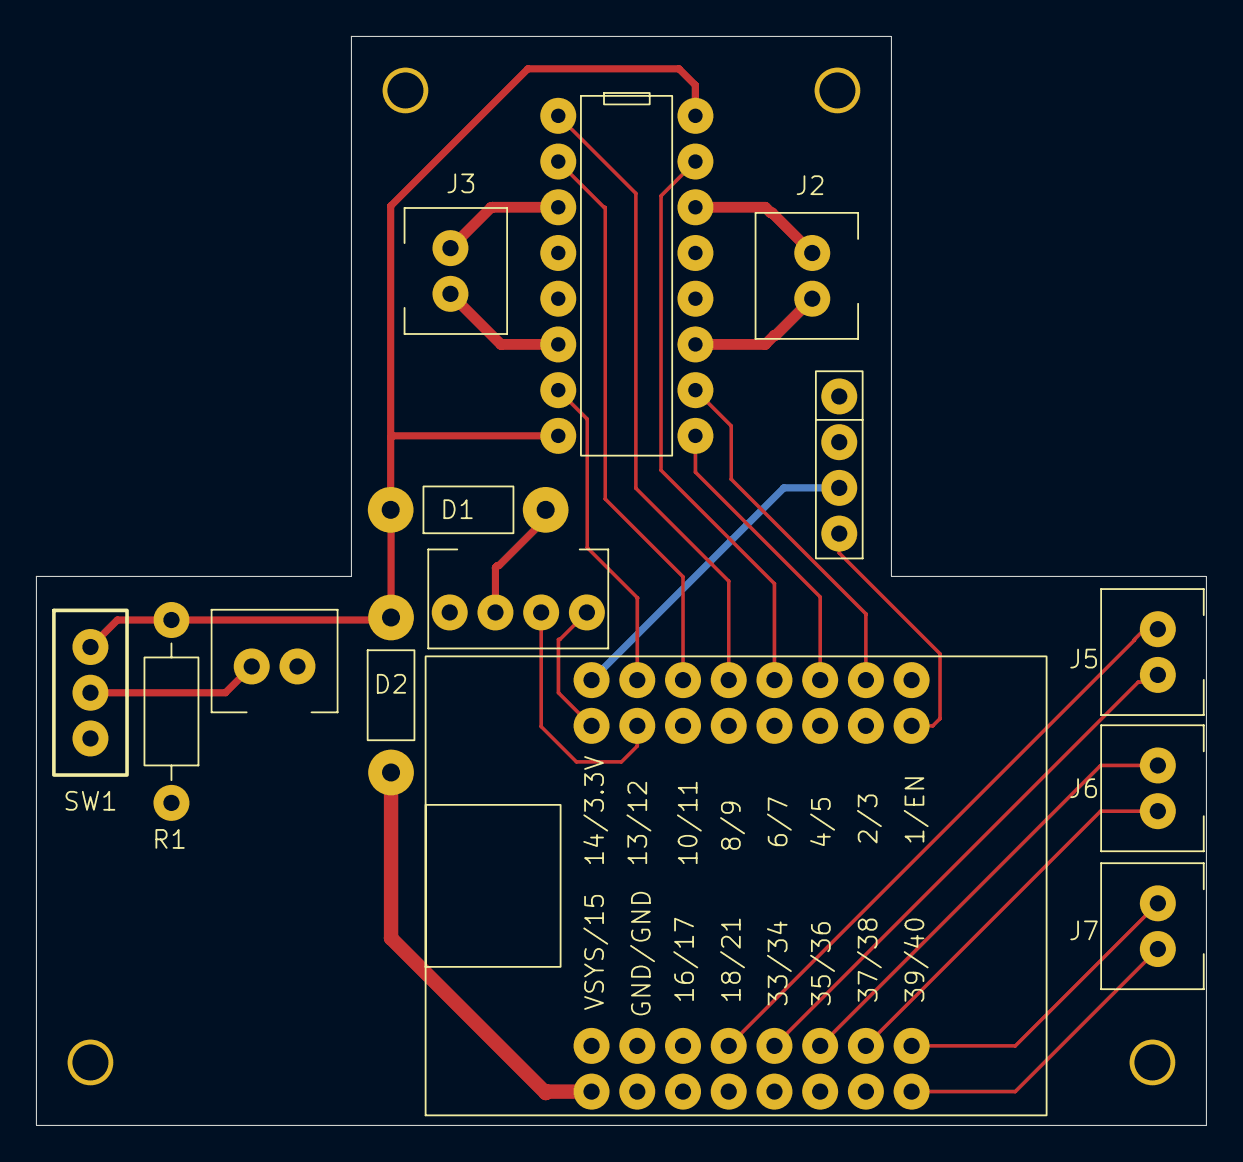
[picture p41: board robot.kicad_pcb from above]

Board: 2 copper layers, 65.0 x 60.5 mm, 18 parts (0 on the bottom side), 25 nets.

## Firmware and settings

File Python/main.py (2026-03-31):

# put your code here
#
#  mac_addr =   # this device

from mac_addr import *

num, cpu = find_robot()
if cpu == "telecommande":
    print("telecommande", num)
    import png
    import telecommande
elif cpu == "robot":
    print("Robot", num)
    import robot
else:
    print("esp_receive")
    import esp_receive
    

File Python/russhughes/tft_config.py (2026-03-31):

""" LilyGo T-DISPLAY 135x240 ST7789 display
    see : https://github.com/russhughes/st7789_mpy
    
    NOTE: Reduce the SPI baudrate below 26.7MHz unless you are using my compiled firmware or you modify
    the spi_device_interface_config_t devcfg.flags setting in the micropython/ports/esp machine_hw_spi.c
    file to include the SPI_DEVICE_NO_DUMMY flag.
    for example change line 262 in micropython/ports/esp32/machine_hw_spi.c from this:
        .flags = self->firstbit == MICROPY_PY_MACHINE_SPI_LSB ? SPI_DEVICE_TXBIT_LSBFIRST | SPI_DEVICE_RXBIT_LSBFIRST : 0,
    to this:
        .flags = self->firstbit == MICROPY_PY_MACHINE_SPI_LSB ? SPI_DEVICE_TXBIT_LSBFIRST | SPI_DEVICE_RXBIT_LSBFIRST : 0 | SPI_DEVICE_NO_DUMMY,
    Recompile and flash the firmware and you can use the 40MHz speed.
"""
from machine import Pin, SPI
import st7789

TFA = 40
BFA = 40

def config(rotation=0, buffer_size=0, options=0):
    spi = SPI(2, baudrate=40_000_000, sck=Pin(18), mosi=Pin(19), miso=None)
    width, height = 135, 240
    return st7789.ST7789(spi, width, height,
        reset=Pin(23, Pin.OUT),      # chip hard reset
        cs=Pin(5, Pin.OUT),          # chip select pin
        dc=Pin(16, Pin.OUT),         # data/command pin
        backlight=Pin(4, Pin.OUT),   # backlignt pin (often left floating)
        rotation=rotation,           # 0=portrait, 1=landscape(90°), 2=reverse prtrait(180°), 3=reverse landscape(270°)
        options=options,             # 0=no wrap, 1=wrap vertically, 2=wrap horizontally, 3=wrap both
        buffer_size= buffer_size)

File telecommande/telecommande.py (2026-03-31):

import network
import espnow
from machine import Pin, ADC
from time import sleep_ms, ticks_ms
# from neopixel import NeoPixel
from mac_addr import robot_mac, telecommande_mac

#
num = 1
robotAddr = robot_mac[num]

#
# red, green, blue, white, black = (0, 128, 0), (128, 0, 0), (0, 0, 128), (32, 32, 32), (0, 0, 0)

#
def normalize(x, amp=100):
    ''' resize x -> [-amp;+amp] '''
    x -= midadc
    if x > dzw:
        x = int(amp*(x-dzw)/szw)
    elif x < -dzw:
        x = int(amp*(x+dzw)/szw)
    else:
        x = 0
    return x
#
def constrain(x):
    return min(max(x, -100), 100)

# init ADC
a0 = ADC(Pin(39, Pin.IN), atten=ADC.ATTN_11DB)
a1 = ADC(Pin(36, Pin.IN), atten=ADC.ATTN_11DB)
midadc = 1730         # adc middle
maxadc = 3150         # adc max
dzw    = 200          # dead zone width
szw    = midadc - dzw # sensitive zone width
samp   = 100
ramp   = 50

# init neopixel
# np = NeoPixel(Pin(5, Pin.OUT),1)
# np[0] = (8, 8, 8)
# np.write()

# A WLAN interface must be active to send()/recv()
sta = network.WLAN(network.STA_IF)  # Or network.AP_IF
sta.active(True)
sta.disconnect()      # For ESP8266

# init espnow
e = espnow.ESPNow()
e.active(True)
print("telecommande.py : Network active, Espnow ok")

try:
    e.add_peer(robotAddr)      # Must add_peer() before send()
except:
    pass
print("telecommande.py : robot added to peers")
#
while True:
    try:
        r, s = a0.read_uv()/1000, a1.read_uv()/1000
        r = normalize(r, ramp)     # r in [-ramp,+ramp]
        s = normalize(s, samp)     # s in [-samp,+samp]
        ls, rs = constrain(s+r), constrain(s-r)
        cmd = 'ml.set_speed(' + str(ls) + ')\r'
        cmd += 'mr.set_speed(' + str(rs) + ')\r'
        e.send(robotAddr, cmd.encode(), False)
        print(cmd.encode())
        sleep_ms(100)
    except:
#         np[0] = red
#         np.write()
        break 

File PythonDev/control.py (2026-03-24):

import network
import espnow
import _thread
import server
import re
import time
import ujson

# --- Configuration ESP-NOW ---
sta = network.WLAN(network.STA_IF)
sta.active(True)
e = espnow.ESPNow()
e.active(True)

# Adresse MAC de l'ESP32 + K210 (à remplacer)
peer_mac = b'\xAA\xBB\xCC\xDD\xEE\xFF'
e.add_peer(peer_mac)

# Liste des panneaux détectés
detected_signs = []

# Callback pour recevoir les messages ESP-NOW
def espnow_receive():
    global detected_signs
    while True:
        if e.any():
            mac, msg = e.recv()
            if msg:
                sign_id = msg.decode('utf-8').strip()
                try:
                    m = re.match(r"([\d])[:].*", sign_id)
                    sign_id = f"p{int(m.group(1)) + 1:02d}"
                    print("Panneau reçu:", sign_id)
                    robot.detect_sign(sign_id)
                    send_sse_event(sign_id)
                except:
                    pass

# Démarrage du thread de réception ESP-NOW
_thread.start_new_thread(espnow_receive, ())

sse_clients = set()

def handle_sse(conn):
    print("Nouvelle connexion SSE établie !")
    sse_clients.add(conn)
    try:
        while True:
            time.sleep(1)
    except:
        sse_clients.remove(conn)

def send_sse_event(data):
    print(f"Envoi SSE : {data} à {len(sse_clients)} clients")
    for conn in sse_clients:
        try:
            conn.send(f"data: {data}\n\n")
        except:
            sse_clients.remove(conn)

#====================  Classe Robot

class Robot:
    def __init__(self):
        self.etat = 0  # -1: recule, 0: arrêté, 1: avance
        self.speed = 1  # 1 ou 2

        self.start_time = None
        self.penalties = 0
        self.game_active = False
        self.detected_signs = set()
        self.required_signs = {"p30", "pietons", "cedez_le_passage", "priorite_a_droite", "stationnement", "stop", "start"}
        self.required_signs_id = {"p05", "p03", "p04", "p02", "p01", "p06", "p07"}
        self.stop_time = None

    def start_game(self):
        self.start_time = time.time()
        self.game_active = True
        self.penalties = 0
        self.detected_signs.clear()
        print("Jeu démarré !")

    def stop_game(self):
        if self.game_active:
            self.stop_time = None
            self.game_active = False
            print("Jeu terminé !")

    def add_penalty(self, seconds):
        self.penalties += seconds
        print(f"Pénalité ajoutée : {seconds} secondes")

    def detect_sign(self, sign_id):
        if self.game_active and sign_id in self.required_signs_id:
            self.detected_signs.add(sign_id)
            print(f"Panneau détecté : {sign_id}")

            # Règles de pénalités
            if sign_id in ["p03", "p04", "p02"]:
                if self.etat != 0:
                    self.add_penalty(5)  # 5 secondes de pénalité si on ne s'arrête pas
            elif sign_id in ["p05"]:
                if self.speed != 1:
                    self.add_penalty(3)  # 3 secondes de pénalité si vitesse incorrecte
            elif sign_id == "p01":
                if self.etat == 0:
                    self.add_penalty(2)  # 2 secondes de pénalité si arrêté
            elif sign_id == "p06":
                self.stop_game()

    def get_elapsed_time(self):
        if self.start_time is None:
            return 0
        if self.stop_time is not None:
            return self.stop_time - self.start_time
        return int(time.time() - self.start_time)

    def get_total_score(self):
        if self.start_time is None:
            return 0
        return int(self.get_elapsed_time() + self.penalties)

    def get_penalties(self):
        return int(self.penalties)

    def set_etat(self, nouvel_etat):
        if nouvel_etat in [-1, 0, 1]:
            self.etat = nouvel_etat
            print(f"État du robot mis à jour : {self.etat}")
        else:
            print(f"État invalide : {nouvel_etat}")

    def set_speed(self, nouvel_speed):
        if nouvel_speed in [1, 2]:
            self.speed = nouvel_speed
            print(f"Vitesse du robot mis à jour : {self.speed}")
        else:
            print(f"Vitesse invalide : {nouvel_speed}")

    def get_etat(self):
        return self.etat

    def get_speed(self):
        return self.speed
    
    def get_combined_etat(self):
        return self.etat * self.speed

    def show_etat(self):
        return f"État : {self.get_etat()} Vitesse : {self.get_speed()}"

robot = Robot()


def get_etat_color(etat, speed):
    combined_etat = etat * speed
    colors = {
        -2: "#FF6347",  # Tomate (Recule vite)
        -1: "#FFA07A",  # Saumon (Recule lentement)
        0: "#32CD32",   # Vert lime (Arrêt)
        1: "#4169E1",   # Bleu royal (Vitesse 1 avant)
        2: "#1E90FF"    # Bleu dodger (Vitesse 2 avant)
    }
    return colors.get(combined_etat, "#808080")  # Gris par défaut



#====================  HTML avec carte de fond et animations

"""
        .boutons-commande {
            display: flex;
            flex-wrap: wrap;
            gap: 8px;
        }
"""
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

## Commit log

2025-12-28 Tests esp-now entre 2 ESP32S3
2025-12-29 Tests esp-now entre 2 ESP32S3 arrêt CTL-C controllé
2026-01-17 Tests communication série entre 2 ESP32 et K210
2026-01-17 Commandes pour la capture d'images associées à N identifiants
2026-01-17 images de panneaux
2026-01-24 Ajoute de la documentation Sipeed
2026-01-24 Ajoute un pgm de test de la caméra
2026-01-24 Apprentissage: initialisation des classes
2026-03-03 Add README.md for Kicad PCB files
2026-03-03 Change PCB image to electrical schematic image
    Updated image source in README for robot PCB.
2026-03-03 Add image to README for telecommande PCB
2026-03-16 Add README.md for robot 3D printing files
2026-03-16 Reprise des développements depuis le dossier ESP32S3Cam
2026-03-24 Mise en place de la base avec la technologie des événements SSE
2026-03-24 Mise en place de la base avec la technologie des événements SSE les messages espnow générent des evt SSE pour être exploités dans le client
2026-03-26 Mise en place de la gestion à deux joueurs et donc avec deux robots.
2026-03-26 Mise en place de la gestion à deux joueurs et donc avec deux robots. Les clicks et le messages espnow sont équivalents
2026-03-31 finalisation des fichiers à installer
2026-03-31 finalisation des fichiers à installer prépare un dossier Python d'installation en préservant les anciens fichiers en développement
2026-05-06 Protocole de broadcast pour que la base détecte les mac adresses des robots, et pour que chaque robot reçoivent la mac adresse de la base.
2026-05-11 Ajout du mécanisme de broadcast pour rendre l'initialisation des robots, base, télécommandes sans mémoriser la mac-add de la base
2026-05-12 Par défaut, on est en mode simulation de robots simulés. Dès qu'un robot se connecte, on débranche le mode simulation. De même, le bouton reset simule 2 robots si la simulation est ON. Le bouton rese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
    [base.py]
2026-05-19 debugging connection des robots, association des robots avec l'IHM dans base
